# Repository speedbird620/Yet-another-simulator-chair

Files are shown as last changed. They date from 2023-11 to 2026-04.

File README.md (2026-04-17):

# Yet another simulator chair

## Abstract 

This is an open source simulator project where an IKEA chair has been modified into a dual control joystick. The primary purpose is to provide students with an opportunity to train, for example, using Condor gliding simulator. From the basic flight training, to fine tuning the art thermalling and cross country. All in reach for the reasonable DIY-handy individual.

Note that the chair can easily be used for both motor and rotorcraft as well: you simply tighten the wing nut and neutralize the spring that simulates the glider´s air brake return force.

## Background

This project is sprang from the disappointment of using a joystick bought from an electronics store for 120€. Being a glider pilot for the last +30 years I do become annoyed when I can´t catch the thermals properly in the Condor gliding simulator. Or at least I blamed the joystick.

I started to think outside the box: How can I do this better with a reasonable budget? This page is my answer to this question.

After a few prototypes, I arrived at a solution where a control assembly is mounted on a chair. The prototypes proved that adequate control was feasible with surprisingly good flight control dynamics: you tend to forget that you are in a simulator when using a VR-headset. 

_The first example in the prototype series during flight trials._





_The first example in the prototype series being built._



The second iteration is utilising an Arduino Micro and hall sensors for the flight controls. Then an idea emerged of creating a more comfortable solution which can be reproduced larger numbers and how simulators can be a part of pilot training, especially for us who lives in a country that only allow flight from April to October.

The requirements for the simulator:
 - The parts shall be available in general stores (as far as possible)
 - A simple yet durable construction
 - Dual control: stick, rudder and airbrake
 - Airbrake shall be able to be used as throttle and collective after minor alteration
 - Tow cable release
 - Position of pedals are adjustable

## Current project status

The list of built YAS-chairs:
- sn 001: ÖSFK at ESSZ, first prototype
- sn 002: Private outside Långtora, second prototype.

Follow the progress of sn 002 here: https://photos.google.com/share/AF1QipPOUyROssQ330J8llb0_tj2pAIGFBXjLDJpcaH-N3GVbZG6ntuDcigQtvq15HF2ng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

Prototype series sn 003 - 010:
- sn 003: Swedish Soaring Federation, Ålleberg
- sn 004: Private, Forssa
- sn 005: Private, Forssa
- sn 006: Private, Forssa
- sn 007: Private, Ludvika
- sn 008: Borås Segelflygklubb
- sn 009: kit available
- sn 010: kit availablel

_The assembly process of sn 003. For pictures in a sort of a timeline, se assembly.pfd above._








_Second prototype, sn 002._



_Airbrake and tow release of second prototype, sn 002._



## Electronics, "the magic stuff"

The electronics and software package that will simulate a joystick using the built-in drivers in Windows. Either you can get the stuff in the bill of materials, put things together and apply the Arduino libraries. Or feel free to use it as a creative compass for your own build.

The skill level required is an average glider pilot with limited soldering skill. After all this aren’t rocket science, just simulator science.

The electronics and software package contains:
 - Design schematic (open source) for Arduino Leonardo or Arduino Micro (ATMEGA32U4)
 - Software and libraries (open source)
 - Bill of material for recommended components to order 

Please note: At first, I used potentiometers which broke pretty much instantly. Since then hall sensors are used which works excellently. So, if you are opting for potentiometers, please be aware of the potential limitations.

To make things easier I have developed a bespoke PCB-adaptor between Arduino and electrical connectors as well as a bespoke PCB-adaptor for the hall sensors recommended in the bill of material. Eventually you will be able to order these PCB´s.

_PCB for adaptor Arduino and hall sensor._



_PCB-adaptor for Arduino Leonardo or Arduino Micro. The picture shows a PCB with Leonardo, hall sensor and switches (examples)._



## Flight control assembly

The flight control assembly is designed to fit onto a [POÄNG](https://www.ikea.com/se/sv/cat/poaeng-serie-07472/) from IKEA. Please see the blue prints in the DXF-folder in the file repository above for the pieces to cut out. Above you will also find a list of material to buy in the local hardware store (hinges, washers, nuts, screws, bicycle parts etc.)

We plan to offer a kit with CNC-cutout parts from plywood but this is progress right now. Meanwhile, if you have access to a CNC machine or a laser cutter, please feel free to download the DXF files and make simulator youself.

_The chair with the flight control assembly mounted to POÄNG. View from the side._



_View from back._



_Below are some of the mounting instructions._






Installing the electronics

In order to install the hall sensors, a few 3D printed items have been developed. Please find the STL-files in the above repository. 

_The holder for the Hall-sensor, arm, link and bracket._



_From the back side._



_A base for the PCB so you can test in on a workingbench._



_An overview of the parts to print._



Stay tuned ....

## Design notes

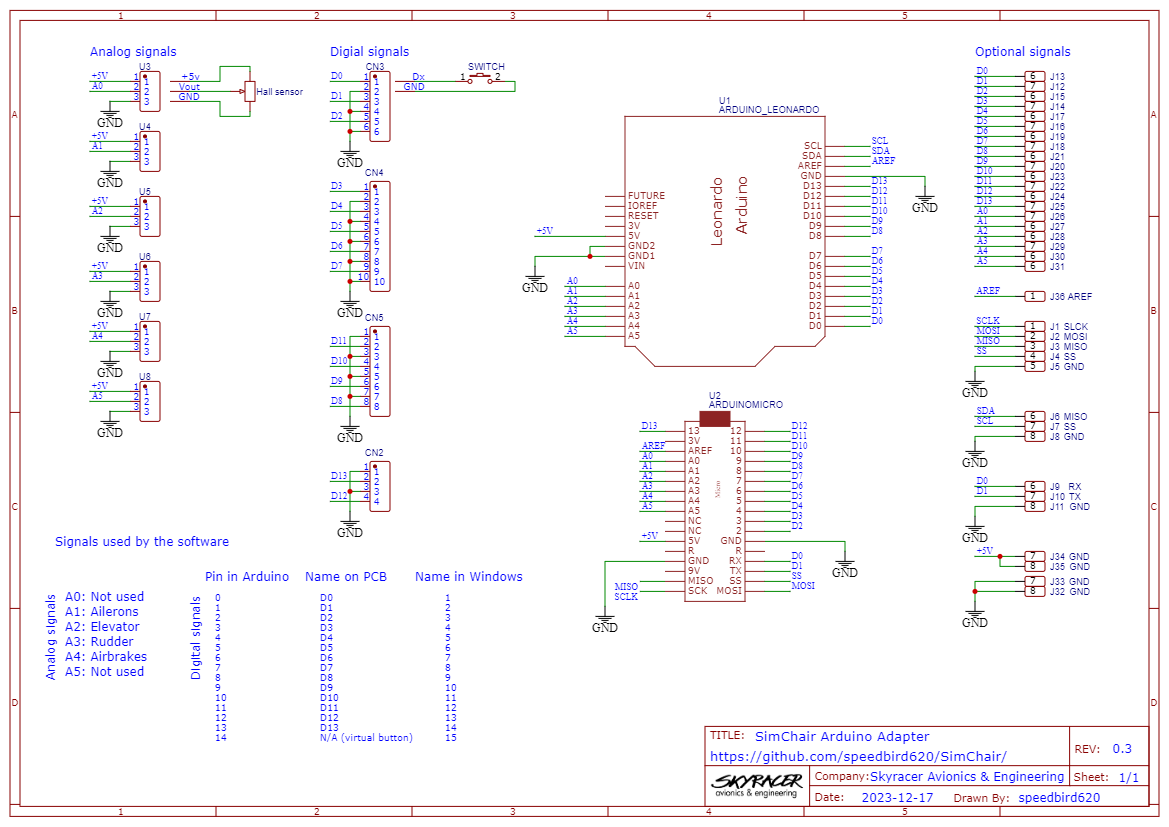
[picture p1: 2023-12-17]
Schematic_SimChair.png

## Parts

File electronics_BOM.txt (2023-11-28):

Description			Vendor	 	Art. No.	Ammount
Terminal block 3 ways		Farnell	 	2493670		12
Terminal block 2 ways		Farnell	 	3810323		14
Tyerminal plug 3 ways		Farnell	 	2575234		12
Tyerminal plug 2 ways		Farnell	 	3810196		14
Pin header, 20 pins		Farnell	 	3881577		2
PCB Receptacle, 12 pins		Farnell	 	1593465		1
PCB Receptacle, 8 pins		Farnell	 	1593463		2
PCB Receptacle, 6 pins		Farnell	 	1668352		1
Wire ferrule 1 mm²		Farnell	 	841201		1
SKX, 2 x 0.75mm2, 25m		Biltema	 	35-433		1
RDO, 3 x 1mm2, 10m		Biltema	 	44-838		1
Hall Effect Sensor, 60°		Farnell		2319671		4
Leonardo			Farnell		2133070		1
USB micro cable			Farnell		2907930		1
Capacitor, 10 µF, 16 V, 0805	Farnell		3013453		4

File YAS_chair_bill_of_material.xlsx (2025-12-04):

Main parts
Description | Vendor | Art. No. | Count | Comment
Poäng | IKEA | 692.408.23 | 1
Plyfa-kit | Högbergs |  | 1
Hardware store stuff
Description | Vendor | Art. No. | Count | Comment
Hinge 1501, 50x39 mm | Habo | 6809 | 7
Wooden joist 1" x 1" | Beijer |  | 2 | 4.2 m, chair guide
Formplywood base plate, 850x2500x12 | Beijer |  | 1
Terminal block 1.5 mm | Biltema | 35-810 | 1 | For securing the bike wires
Rubberbands | Biltema | 34-219 | 1 | ~ 1 m, as pedal springs
Ball bearing, 6000-2RS, 10x26x8 mm | Biltema | 41-412 | 4 | To be encapsulated in 3D-print
Brake wire 1.6mm | Local bike shop |  | 5 | 2 meter brake wire 1.6 mm
Bowden cable 2/6 mm | Local bike shop |  | 2 | Housing the brake wire (2 meters)
Luxorparts Neodyn magnet 8 mm | Kjell.com | 50070 | 2 | Airbrake over-locking
Silicone tube 6 mm x 20 mm | Biltema | 15-330 | 1 | Wheel brake
Wooden glue |  |  | 1 | Not mandantory
Countersunk wooden screw 3.2x20 FXB | Beijer |  | 1 | Pack of 200
Countersunk wooden screw 3.2x35 FXB | Beijer |  | 2 | Pack of 200
Assembly screw 4.2 x 13 mm | Beijer |  | 1 | Pack of 200
Assembly screw 4.2 x 19 mm | Beijer |  | 1 | Pack of 200
M4 x 30 mm Allen screw | Electrokit | 1154354 | 20 | For links to hallsensors
M4 nut | Electrokit | 1874659 | 25 | For links to hallsensors
M6 x 36 carriage bolt |  |  | 1 | Joint for break leaver
M6 wingnut | Biltema | 89-288 | 1 | Joint for break leaver
M6 washer |  |  | 5 | Joint for break leaver
M10x1.5 nut stainless | Biltema | 89-934 | 12 | Stick assembly and rear spedals
M10x1.5 washer stainless | Biltema | 89-423 | 25 | Stick assembly and rear spedals
M10x1.5 threaded rod 1 m | Biltema | 19-340 | 1 | Stick assembly and rear spedals
Cable duct, 12 x 32 x 2000 | Beijer
Misc wooden screws
Electronics
Description | Vendor | Art. No. | Ammount
Terminal block 6 ways | electrokit.com | 41017343 | 2 | For breakout board (switches)
Terminal block 4 ways | electrokit.com | 41017342 | 4 | For breakout board (switches)
Terminal block 3 ways | electrokit.com | 40210022 | 12 | For breakout board (hall sensors)
Terminal plug 3 ways | electrokit.com | 40210012 | 12 | To hall sensors
Terminal plug 2 ways | electrokit.com | 40210011 | 14 | To switches
Slide potentiometer | electrokit.com | 40920011 | 1 | Trim control
Pin header 40 pins | electrokit.com | 41001167 | 2 | For Leonardo
PCB Receptacle 12 pins | electrokit.com | 41010580 | 1 | For breakout board (Leonardo)
PCB Receptacle 8 pins | electrokit.com | 41002450 | 2 | For breakout board (Leonardo)
PCB Receptacle 6 pins | electrokit.com | 41010579 | 1 | For breakout board (Leonardo)
USB micro cable 3 m | electrokit.com | 41015492 | 1 | Leonardo to PC
Wire ferrule 1 mm² | electrokit.com | 41011403 | 150
SKX, 2 x 0.75mm2, 10m | Biltema | 35-433 | 1 | Cable to hall sensors
RDO, 3 x 1mm2, 5m | Biltema | 44-838 | 1 | Cable to switches
Micro switch on-(on) | electrokit.com | 41002040 | 1 | Tow release
Micro switch (on)-off-(on) | electrokit.com | 41015339 | 3 | Flap control, reset, etc.
Pushbutton off-(on) | electrokit.com | 41013042 | 4 | Gear, pause, smoke etc.
Hall Effect Sensor, 60° | Farnell | 2319671 | 4
Leonardo | Farnell | 2133070 | 1
Capacitor, 10 µF, 16 V, 0805 | Farnell | 3013453 | 4 | On the hall sensor PCB
PCB´s
PCB Leonardo | mail@skyracer.net |  | 1
PCB Hall effect sensor | mail@skyracer.net |  | 4
Remote stick PCB | mail@skyracer.net |  | 1
3D-prints
3D-printed brackets (~45 items) |  |  | 1
Remote stick | Langer (Thiniverse) |  | 1 | Optional
Tools
Ferrule crimp tool
Drill 2.5 mm |  |  |  | For pre-drilling so the wood does not crack
Drill 4 mm
Drill 6.5 mm
Drill 8 mm
M3x0.5 thread tap |  |  |  | To clean the threads in 3D printed parts
M4x0.7 thread tap |  |  |  | To clean the threads in 3D printed parts
M10x1.5 thread tap |  |  |  | To clean the threads in 3D printed parts
Set of allen keys |  |  |  | Not just the 4 mm IKEA key
Screwdrivers: PH1, PH2, PZ1, PZ2
2x 15 keys (for the M10 nuts)

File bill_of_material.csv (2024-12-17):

The wood stuff
Base plate 12 mm plywood: 2400mm x 800 mm
Rear POÄNG aligner: 2 pcs 1" x 2" x spar 1400 mm
Front POÄNG aligner: 2 pcs 1" x 2" x spar 900 mm
Flight control stick: 2 pcs 1" x 1" x spar 520 mm
The hardware store stuff
Description | Vendor | Art. No. | Ammount | Comment
Hinge 1501 | 50x39 mm | Habo | 6809 | 14
Ball bearing | Biltema | 41-412 | 4 | 6200-2RS 10x26x8 mm
Terminal block 1.5 mm² | Biltema | 35-810 | 1
Rubberbands | Biltema | 34-219 | 1
Break wire 199 cm | Biltema | 27-802 | 3
Break cable 1.5 mm² | Biltema | 27-804 | 1
Washer M10 stainless 10 pcs | Biltema | 89-934 | 2
Threaded rod M10 100 cm | Biltema | 19-340 | 1
Luxorparts Neodyn magnet 8 mm | Kjell.com | 50070 | 2
PVC-tube 6 mm (inside) x 20 mm | Biltema | 15-330 | 1
The electronics stuff
Description | Vendor | Art. No. | Ammount
Terminal block 6 ways | electrokit.com | 41017343 | 2
Terminal block 4 ways | electrokit.com | 41017342 | 4
Terminal block 3 ways | electrokit.com | 40210022 | 12
Terminal plug 3 ways | electrokit.com | 40210012 | 12
Terminal plug 2 ways | electrokit.com | 40210011 | 14
Slide potentiometer | electrokit.com | 40920011 | 1
Pin header | 40 pins | electrokit.com | 41001167 | 2
PCB Receptacle | 12 pins | electrokit.com | 41010580 | 1
PCB Receptacle | 8 pins | electrokit.com | 41002450 | 2
PCB Receptacle | 6 pins | electrokit.com | 41010579 | 1
USB micro cable 3 m | electrokit.com | 41015492 | 1
Wire ferrule 1 mm² | Farnell | 841201 | 1
SKX, 2 x 0.75mm2, 25m | Biltema | 35-433 | 1
RDO, 3 x 1mm2, 10m | Biltema | 44-838 | 1
Hall Effect Sensor, 60° | Farnell | 2319671 | 4
Leonardo | Farnell | 2133070 | 1
Capacitor, 10 µF, 16 V, 0805 | Farnell | 3013453 | 4

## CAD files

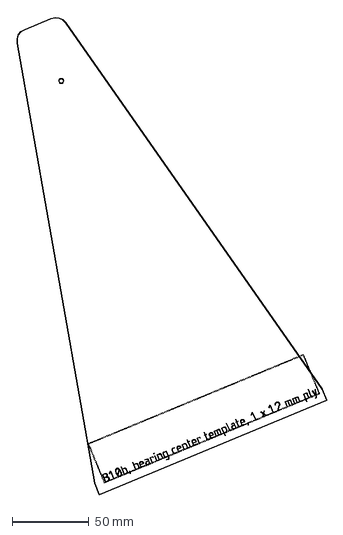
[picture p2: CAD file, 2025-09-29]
dxf/B10b.dxf
202.0 x 310.9 mm

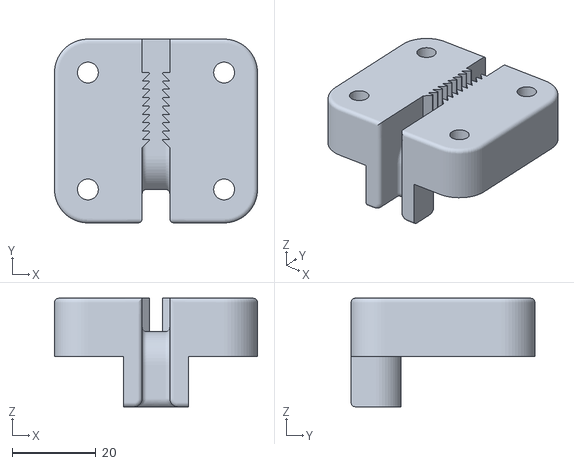
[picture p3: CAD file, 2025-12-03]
stl/G5.stl
48.6 x 44.0 x 26.0

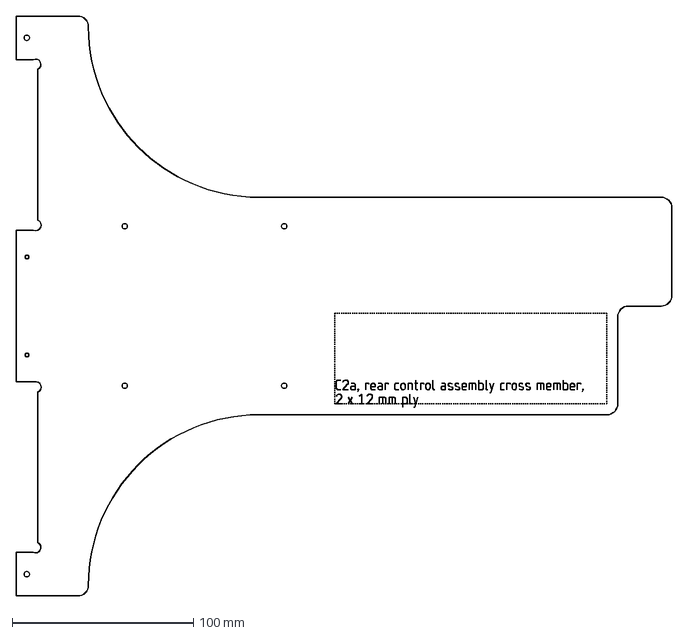
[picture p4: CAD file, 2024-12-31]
dxf/C2a.dxf
362.0 x 320.0 mm

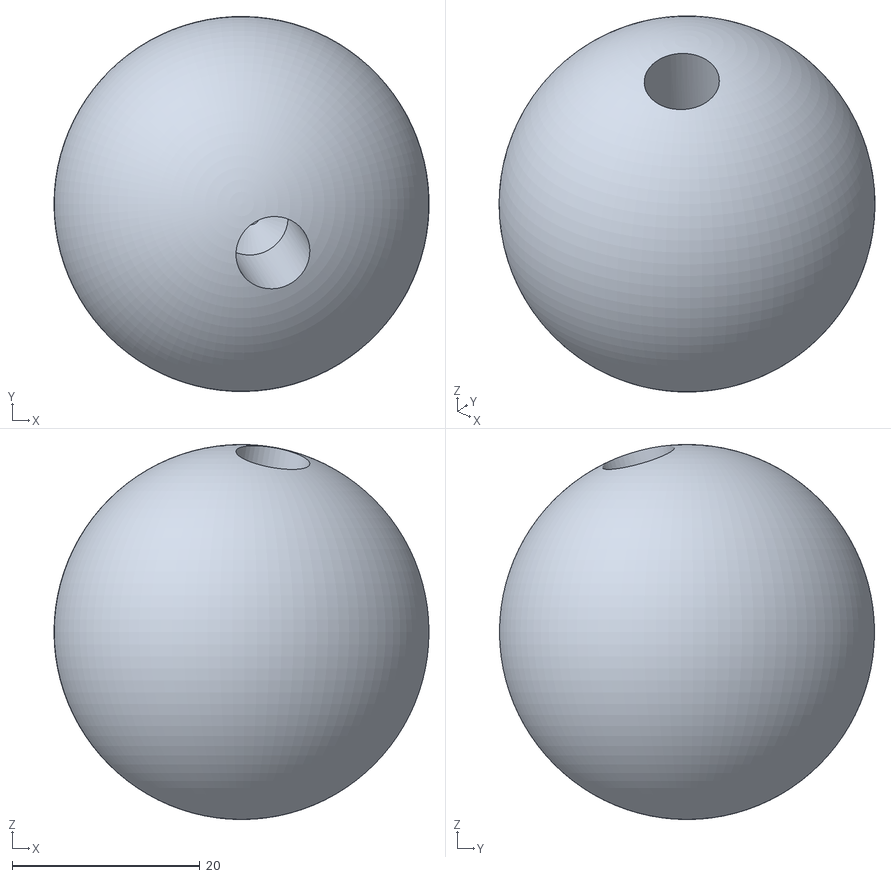
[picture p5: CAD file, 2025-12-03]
stl/H6.stl
40.0 x 40.0 x 40.0

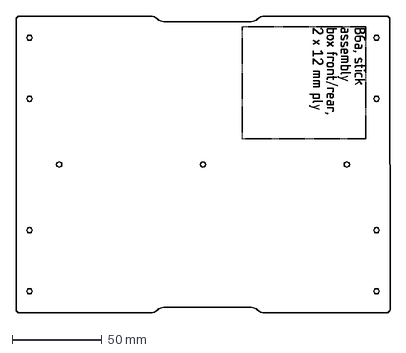
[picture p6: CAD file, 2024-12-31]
dxf/B6a.dxf
208.0 x 165.0 mm

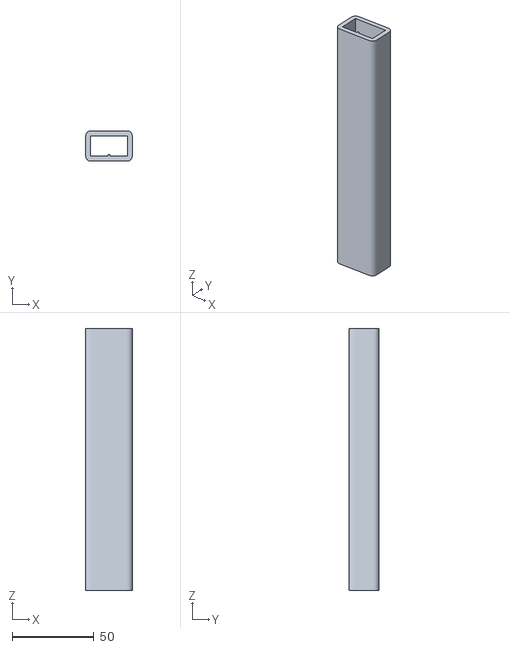
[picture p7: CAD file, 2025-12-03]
stl/H2.stl
28.5 x 18.5 x 160.0

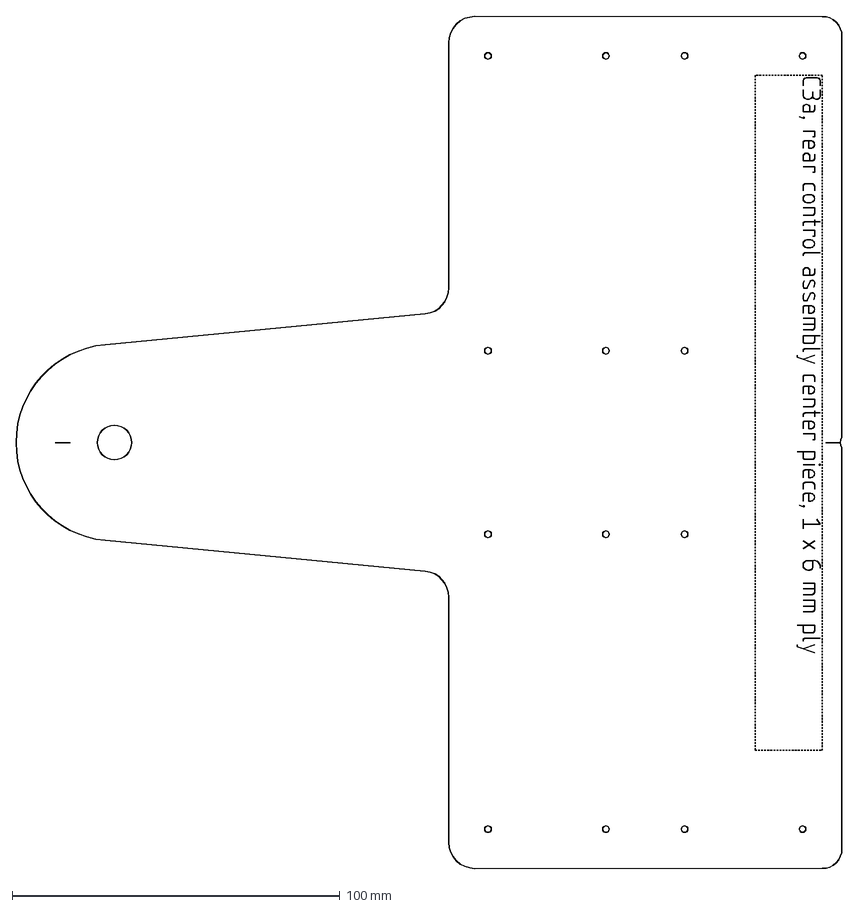
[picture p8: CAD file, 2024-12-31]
dxf/C3a.dxf
252.0 x 260.0 mm

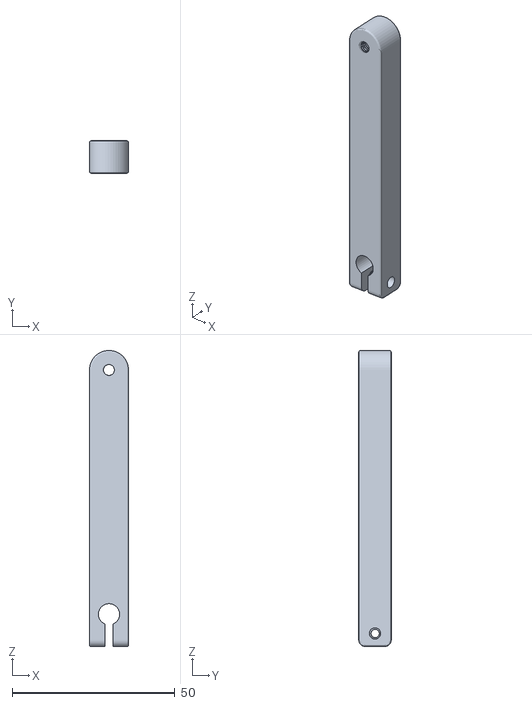
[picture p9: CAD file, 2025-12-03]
stl/F9.stl
12.0 x 10.0 x 90.9

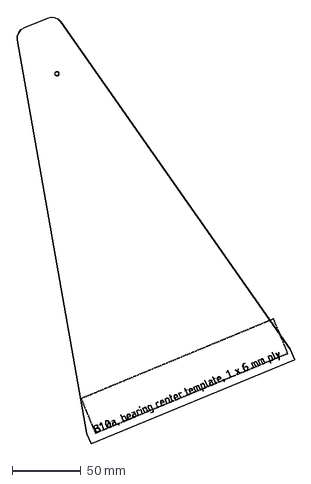
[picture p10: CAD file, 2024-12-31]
dxf/B10a.dxf
202.0 x 310.9 mm

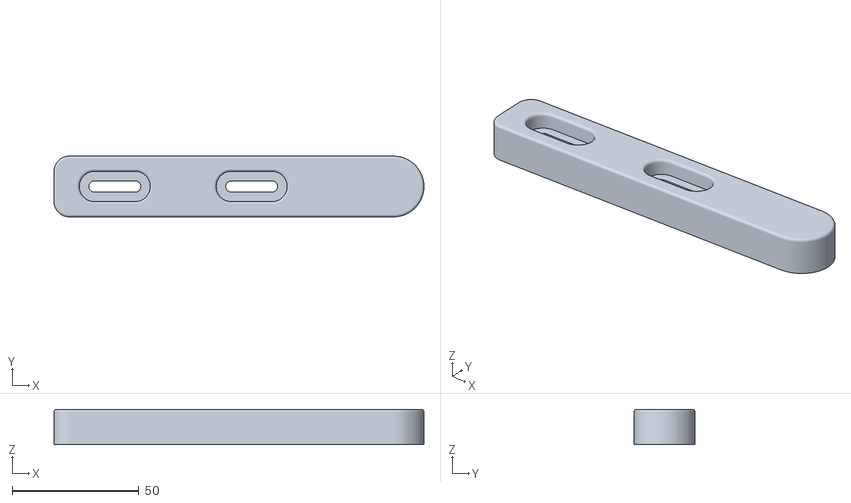
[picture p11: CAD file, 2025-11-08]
stl/G4.stl
146.0 x 24.0 x 14.0

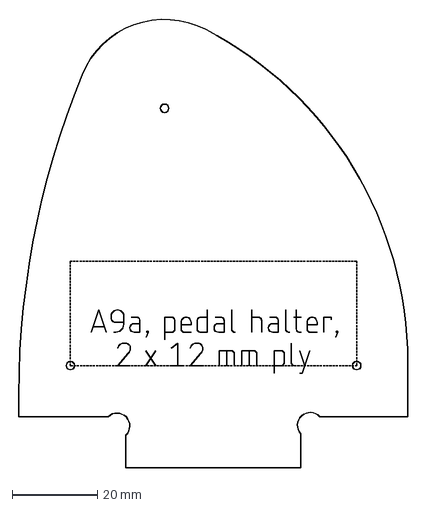
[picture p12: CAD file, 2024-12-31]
dxf/A9a.dxf
91.8 x 106.0 mm

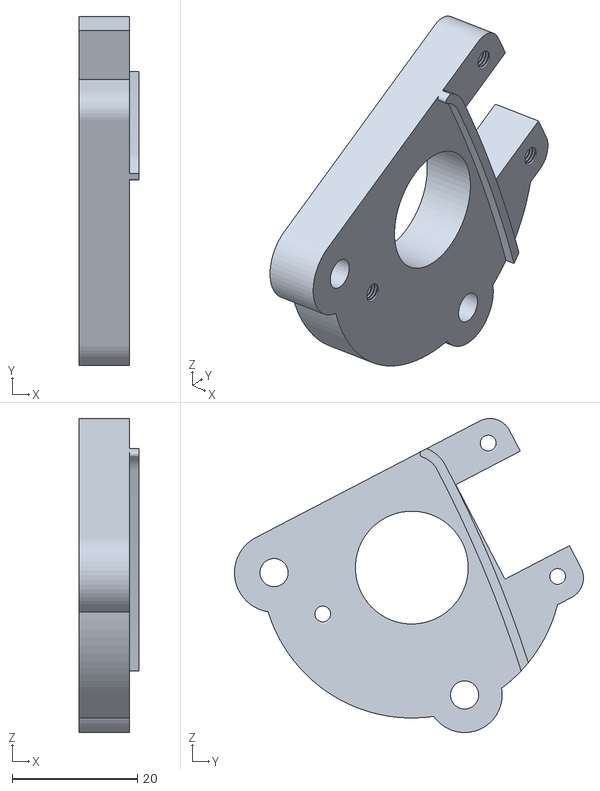
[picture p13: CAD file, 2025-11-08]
stl/F11.stl
9.50 x 55.7 x 50.1

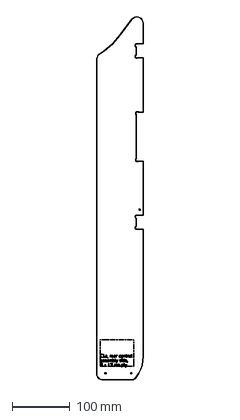
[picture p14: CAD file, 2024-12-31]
dxf/C1a.dxf
80.0 x 628.1 mm

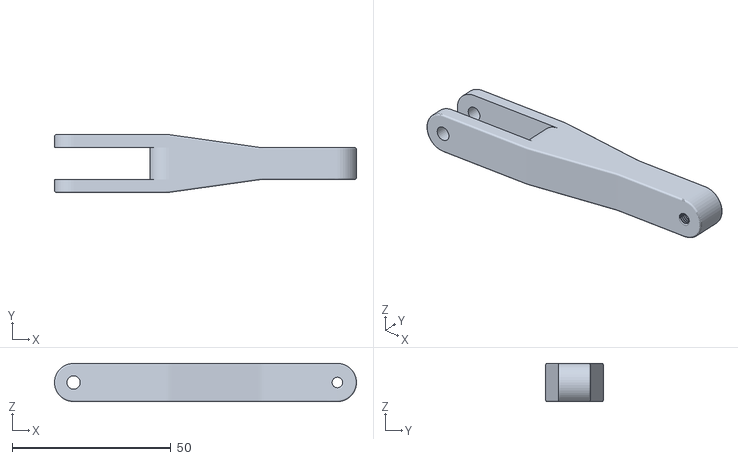
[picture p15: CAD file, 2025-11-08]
stl/F10.stl
95.0 x 18.2 x 12.0

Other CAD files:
dxf/D1a.dxf
stl/F12.stl
dxf/A5.dxf
stl/F3.stl
dxf/A1.dxf
dxf/A2.dxf
dxf/A3.dxf
dxf/A4.dxf
dxf/A6.dxf
dxf/A7.dxf
dxf/A8.dxf
dxf/A9.dxf
dxf/B1.dxf
dxf/B10.dxf
dxf/B2.dxf
dxf/B3.dxf
dxf/B4.dxf
dxf/B5.dxf
dxf/B6.dxf
dxf/B7.dxf
dxf/B8.dxf
dxf/B9.dxf
dxf/C1.dxf
dxf/C2.dxf
dxf/C3.dxf
dxf/D1.dxf
dxf/D2.dxf
dxf/D3.dxf
dxf/D4.dxf
dxf/D5.dxf
dxf/D6.dxf
dxf/E1.dxf
dxf/E2.dxf
dxf/E3.dxf
dxf/E4.dxf
dxf/E5.dxf
dxf/E6.dxf
dxf/E7.dxf
dxf/E8.dxf
dxf/E9.dxf
dxf/old/A1.dxf
dxf/old/A2.dxf
dxf/old/A3.dxf
dxf/old/A4.dxf
dxf/old/A5.dxf
dxf/old/A6.dxf
dxf/old/A7.dxf
dxf/old/A8.dxf
dxf/old/A9.dxf
dxf/old/B1.dxf
dxf/old/B10.dxf
dxf/old/B2.dxf
dxf/old/B3.dxf
dxf/old/B4.dxf
dxf/old/B5.dxf
dxf/old/B6.dxf
dxf/old/B7.dxf
dxf/old/B8.dxf
dxf/old/B9.dxf
dxf/old/C1.dxf
dxf/old/C2.dxf
dxf/old/C3.dxf
dxf/old/D1.dxf
dxf/old/D1a.dxf
dxf/old/D2.dxf
dxf/old/D3.dxf
dxf/old/D4.dxf
dxf/old/D5.dxf
dxf/old/D6.dxf
dxf/old/E1.dxf
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

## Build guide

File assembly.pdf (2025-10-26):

# Please note that the colour of the parts are not consistent in these

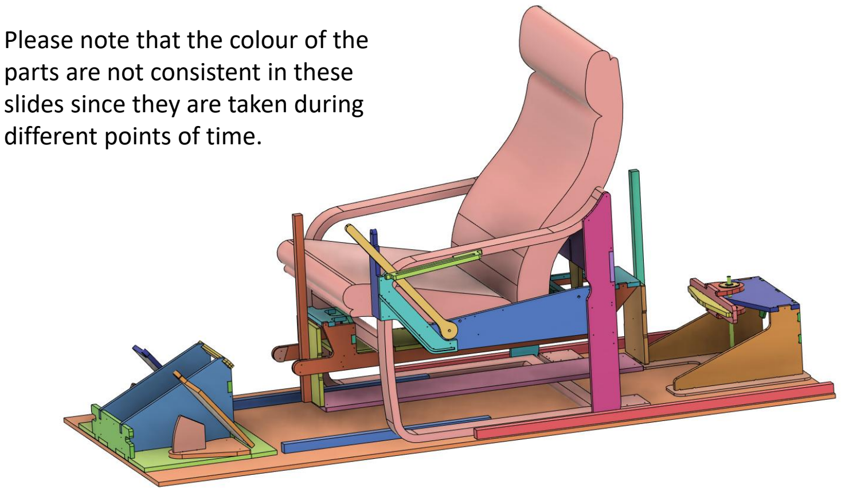
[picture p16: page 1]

# slides since they are taken during

different points of time.

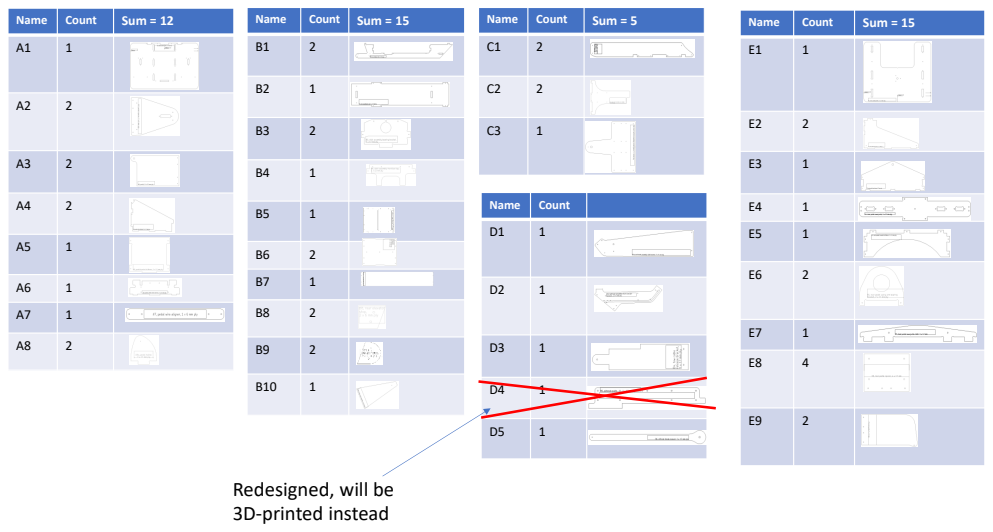
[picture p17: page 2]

F1, 2x

F2, 2x

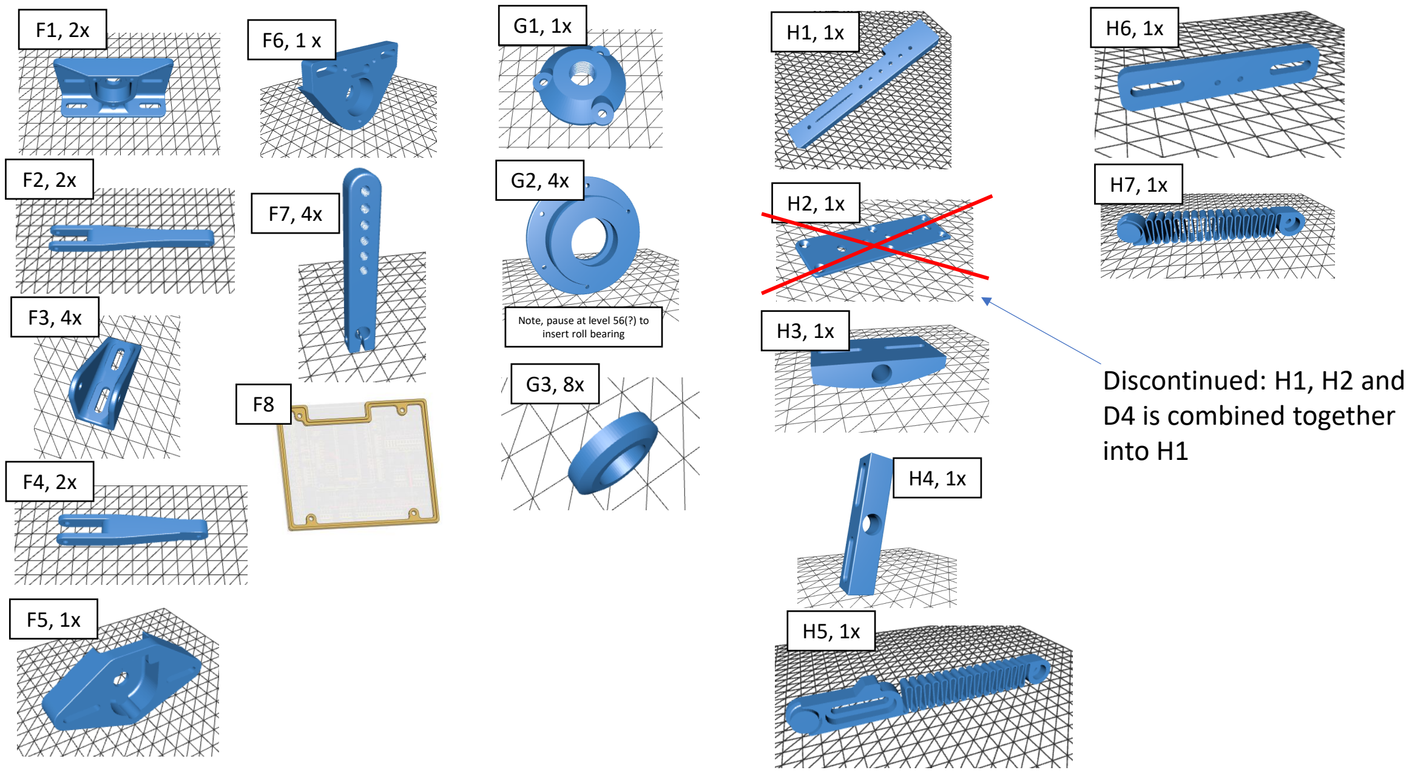
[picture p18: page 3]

F3, 4x

F4, 2x

G1, 1x

G2, 4x

G3, 8x

H1, 1x

H2, 1x

F5, 1x

F6, 1 x

Note, pause at level 56(?) to insert roll bearing

F7, 4x

H3, 1x

H4, 1x

F8

H5, 1x

H6, 1x

H7, 1x

# Discontinued: H1, H2 and D4 is combined together into H1

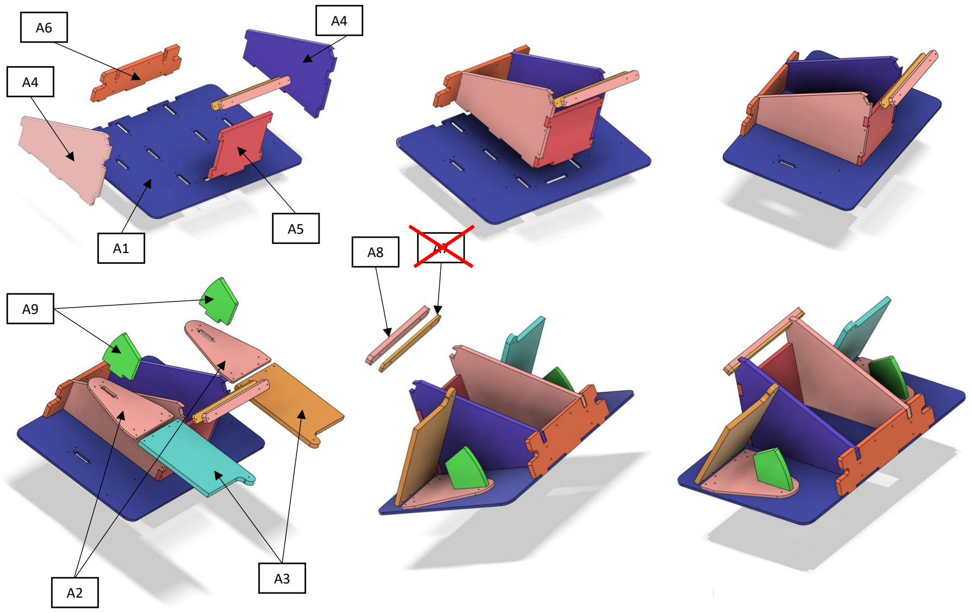
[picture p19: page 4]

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
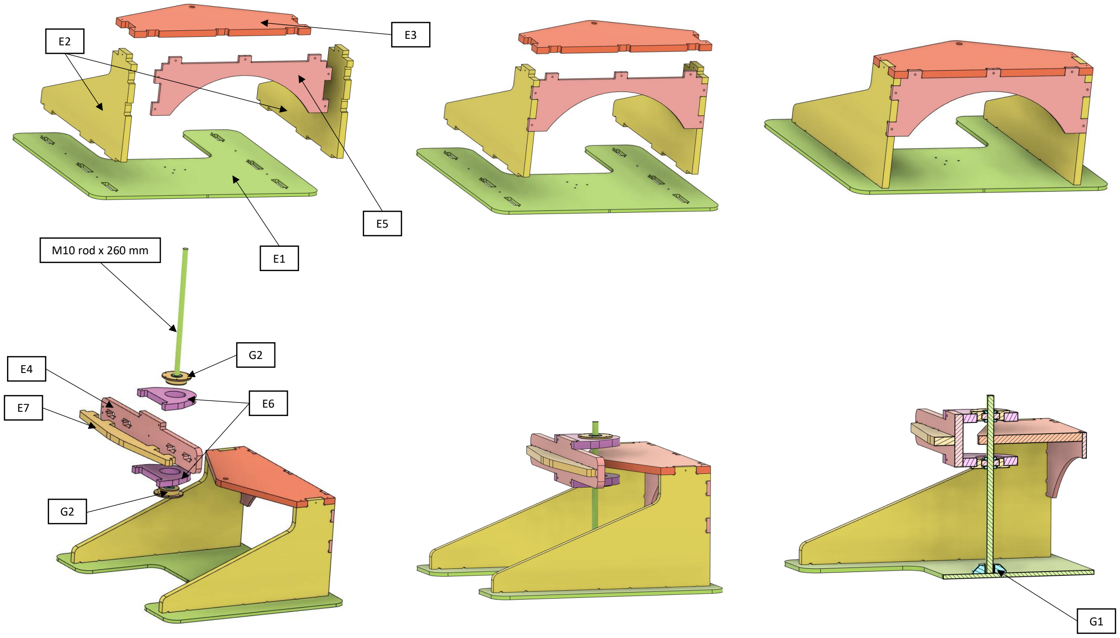
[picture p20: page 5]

E1

E2 | E3

E5

E4

E7 | E6 G2

G2

G1

M10 rod x 260 mm

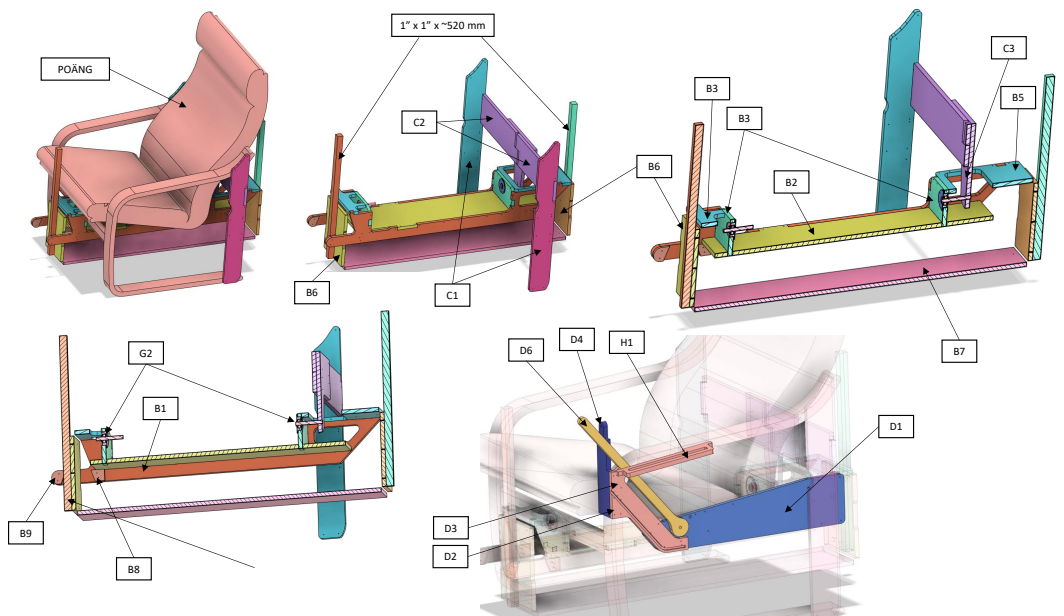
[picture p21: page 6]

This is to simulate the air brake leaver lock.

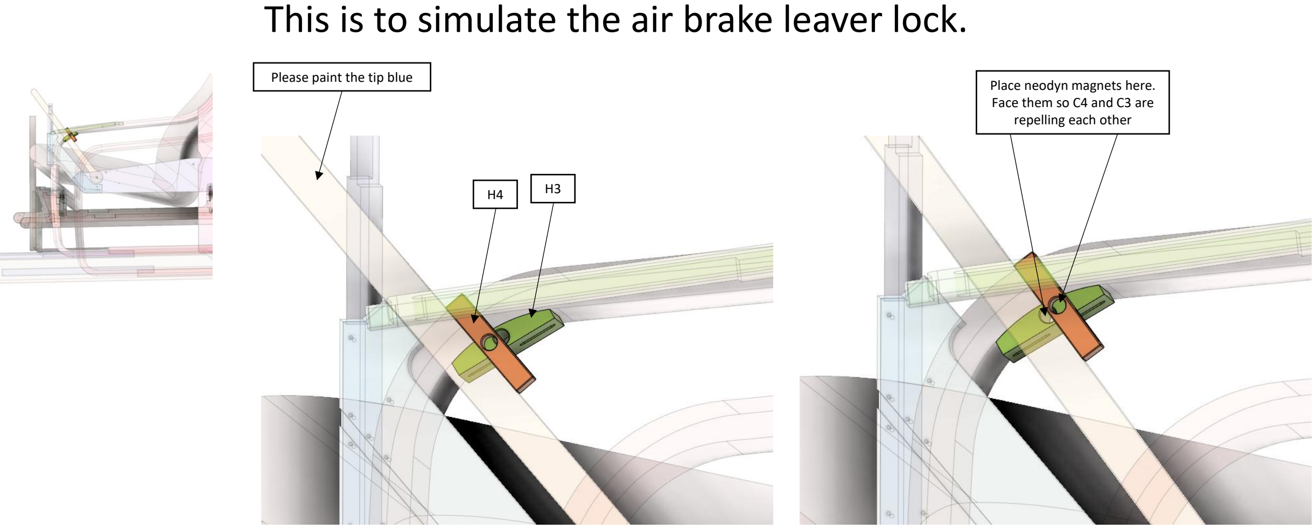
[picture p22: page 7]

H4 H3

Place neodyn magnets here. Face them so C4 and C3 are repelling each other

Please paint the tip blue

# Simulating wheel brake

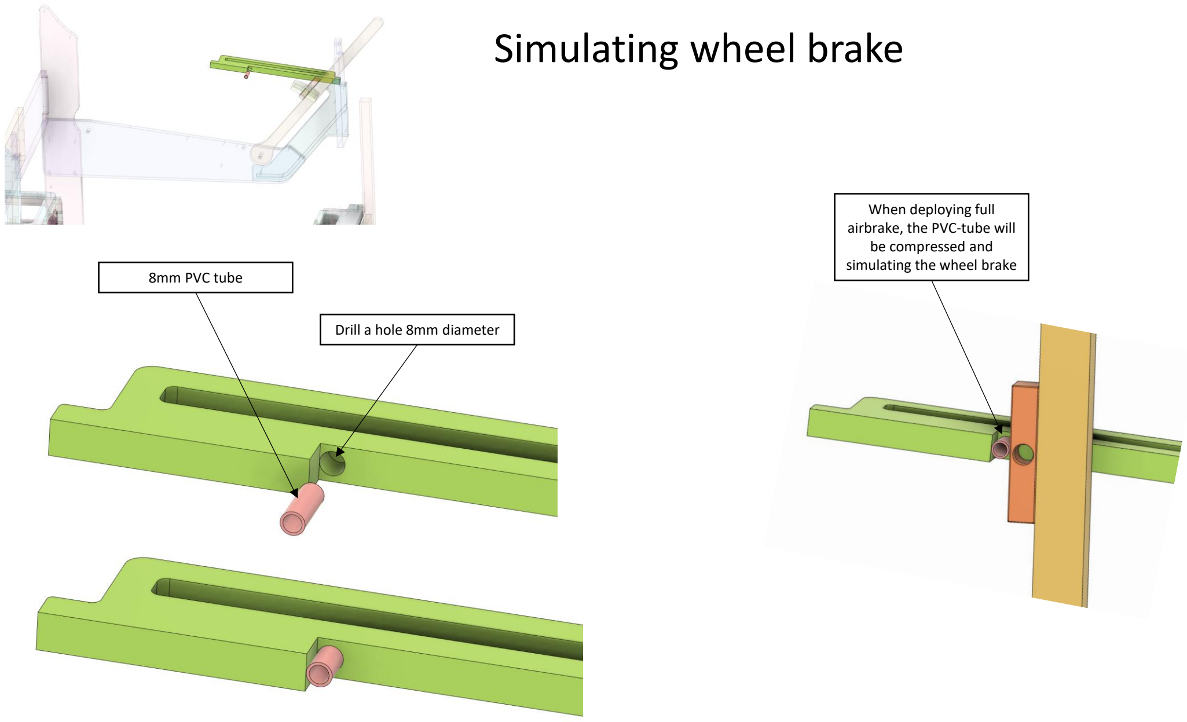
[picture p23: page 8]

Drill a hole 8mm diameter

8mm PVC tube

When deploying full
airbrake, the PVC-tube will be compressed and
simulating the wheel brake

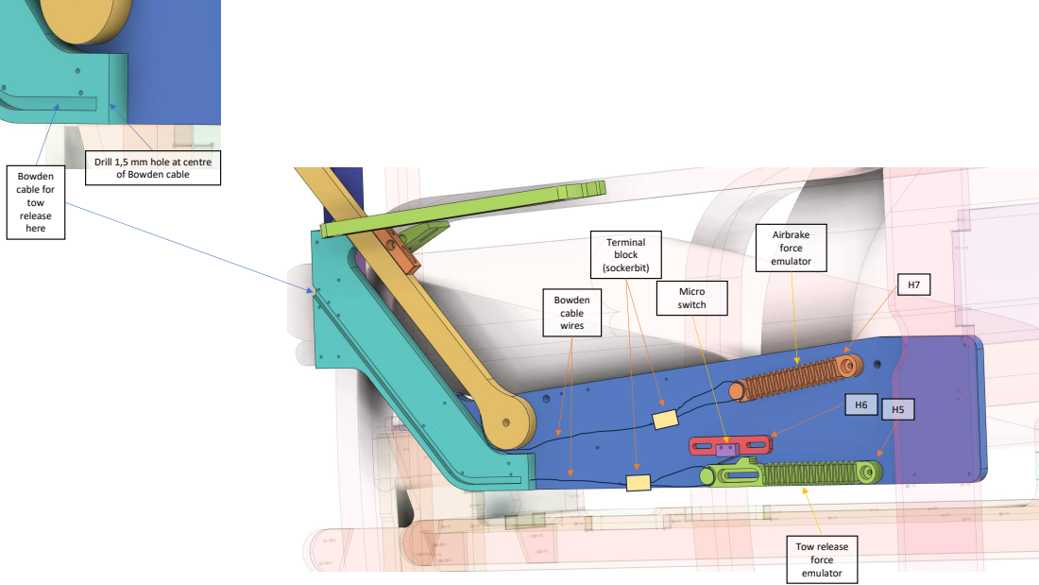
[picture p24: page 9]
Bowden; of Bowden cable; cable for tow release here; Bowden cable wires; Terminal block (sockerbit); Micro switch; Airbrake force emulator; Tow release force emulator

Drill 1,5 mm hole at centre

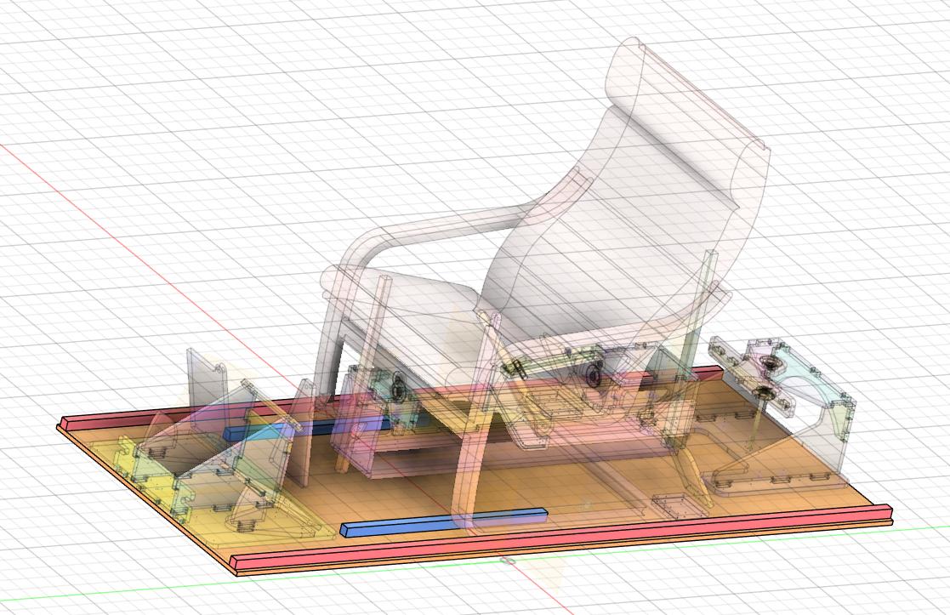
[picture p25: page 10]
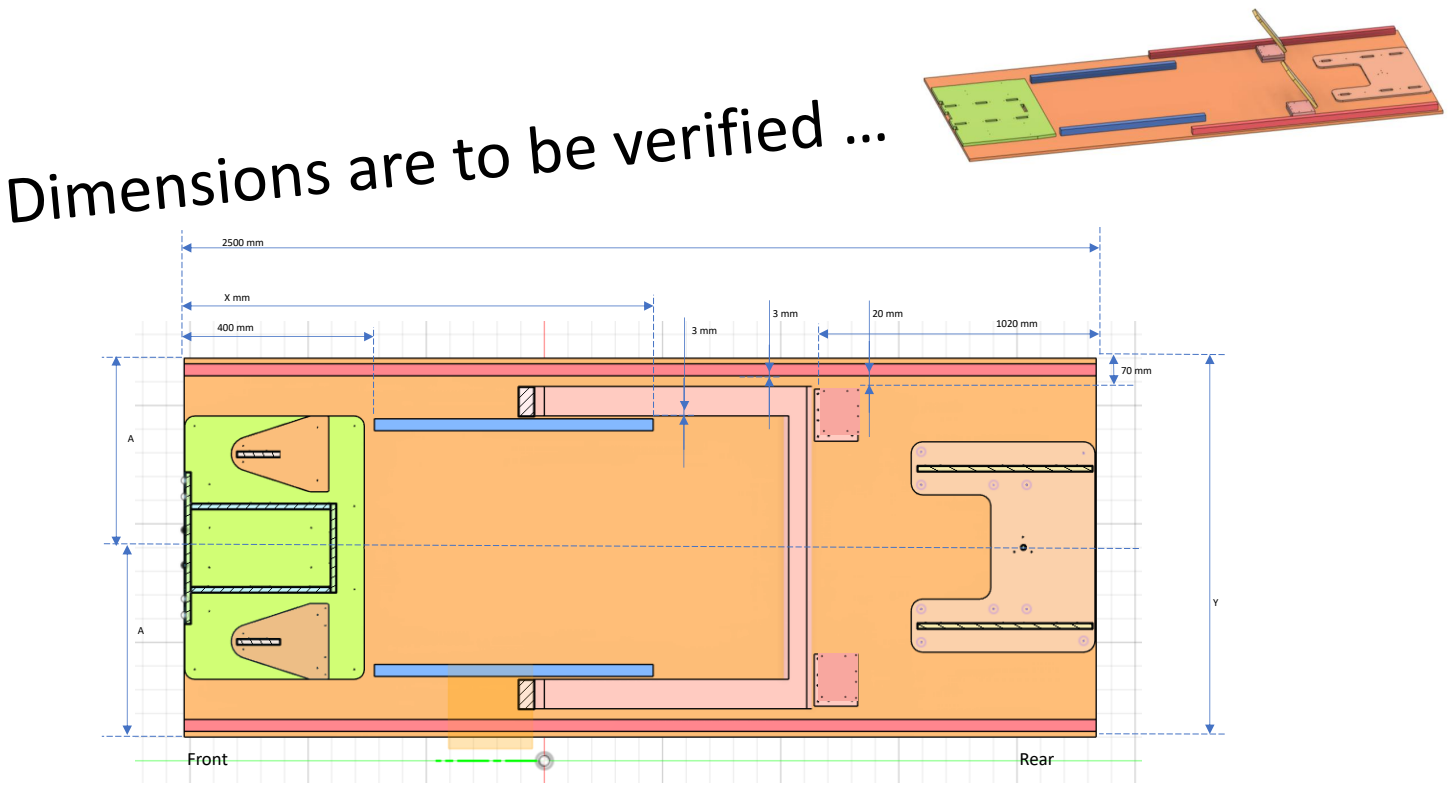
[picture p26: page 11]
Front; Rear

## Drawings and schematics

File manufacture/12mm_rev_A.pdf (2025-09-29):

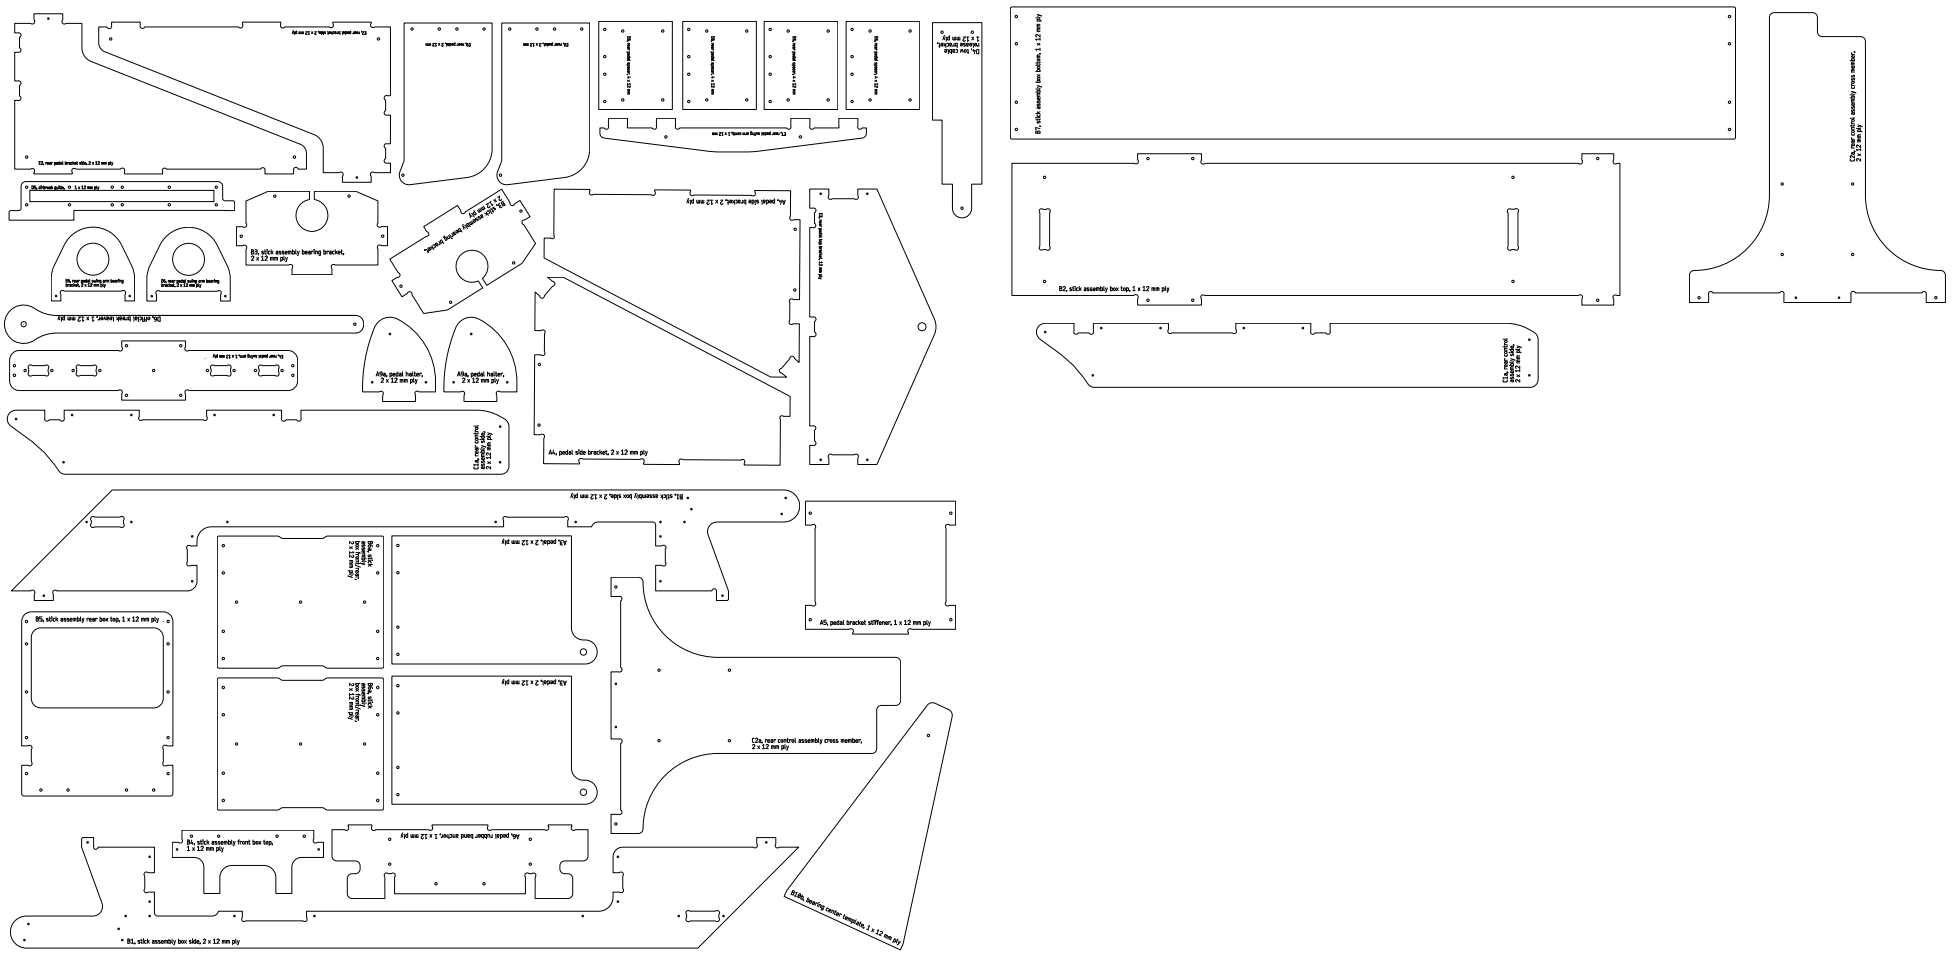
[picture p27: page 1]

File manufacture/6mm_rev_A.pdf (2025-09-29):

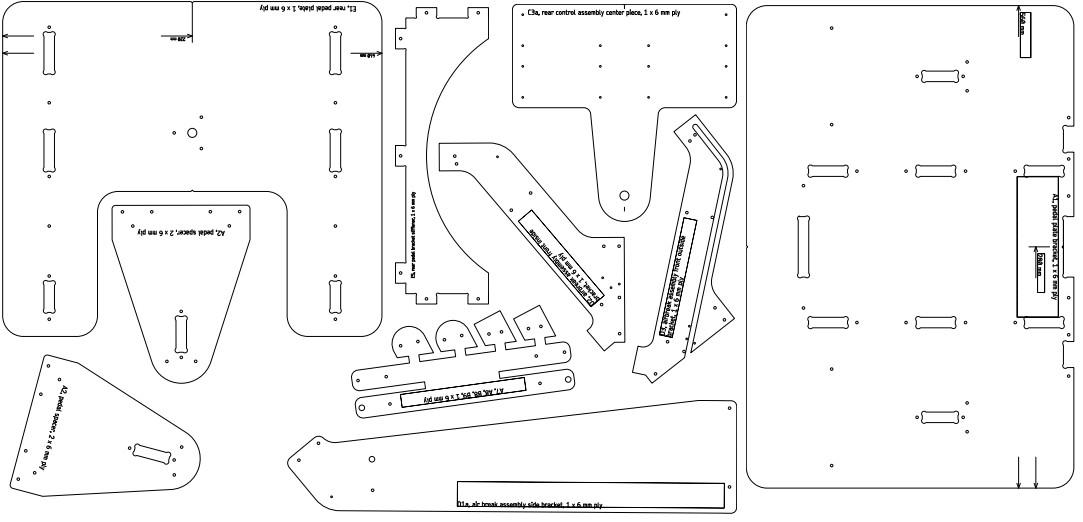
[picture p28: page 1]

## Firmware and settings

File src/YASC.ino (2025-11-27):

// Program bespoke to the SimChair
// Arduino Micro or Leonardo
//
// avionics@skyracer.net
//
// 0.1 - First version
// 0.2 - Added comments and configurable variable
// 0.3 - Added digital signals, now: 15 digital and 4 analog channels
// 0.4 - Added a secondary joysticvk, now: 2 x (15 digital and 4 analog channels)
// 0.5 - Added debug mode
//
// https://github.com/MHeironimus/ArduinoJoystickLibrary/tree/version-1.0
// https://mheironimus.blogspot.com/2015/11/arduino-joystick-library.html
//------------------------------------------------------------

#include <Joystick.h> 

Joystick_ Joystick1(0x03, //hid report id
  JOYSTICK_TYPE_GAMEPAD, //joystick type
  15, //button count
  0, //Hsw 0-2
  true, //x
  true, //y
  true, //z
  false, //rx
  false, //ry
  false, //rz
  false, //rudder
  true, //Airbrake
  false, //throttle
  false, //brake
  false); //steering

Joystick_ Joystick2(0x04, //hid report id
  JOYSTICK_TYPE_GAMEPAD, //joystick type
  15, //button count
  0, //Hsw 0-2
  true, //x
  true, //y
  true, //z
  false, //rx
  false, //ry
  false, //rz
  false, //rudder
  true, //Airbrake
  false, //throttle
  false, //brake
  false); //steering

  // Configuration variables, FALSE: not reverse, TRUE: reversed
  bool XAxisReverse = true;
  bool YAxisReverse = true;
  bool ZAxisReverse = true;
  bool AirbrakeReverse = true;
  bool TrimReverse = false;
  bool WheelBrakeOnAirbrake = true; //Set false if Airbrake is used as throttle
  bool DebugMode = true;

  // Initialize internal variables
  int XAxis = 0;
  int YAxis = 0;
  int ZAxis = 0;
  int Trim = 0;
  int Airbrake = 0;
  int MaxAirbrake = 0;
  int MinAirbrake = 1024;
  float AirbrakeRatio = 0.0;
  
void setup() 
  {
  // Starting the joystick engine
  Joystick1.begin();
  Joystick2.begin();
  // Setting up IO´s
  pinMode(0, INPUT_PULLUP);
  pinMode(1, INPUT_PULLUP);
  pinMode(2, INPUT_PULLUP);
  pinMode(3, INPUT_PULLUP);
  pinMode(4, INPUT_PULLUP);
  pinMode(5, INPUT_PULLUP);
  pinMode(6, INPUT_PULLUP);
  pinMode(7, INPUT_PULLUP);
  pinMode(8, INPUT_PULLUP);
  pinMode(9, INPUT_PULLUP);
  pinMode(10, INPUT_PULLUP);
  pinMode(11, INPUT_PULLUP);
  pinMode(12, INPUT_PULLUP);
  pinMode(13, INPUT_PULLUP);
  }

void loop() 
  {
  //  Reading analog signals

  YAxis = analogRead(A0);
  if (YAxisReverse) {Joystick1.setYAxis(YAxis);}             //  The input is normal (due to mounting of the sensor)
    else {Joystick1.setYAxis(1024-YAxis);}                   //  The input is reversed (due to mounting of the sensor)

  XAxis = analogRead(A1);
  if (XAxisReverse) {Joystick1.setXAxis(XAxis);}             //  The input is normal (due to mounting of the sensor)
    else {Joystick1.setXAxis(1024-XAxis);}                   //  The input is reversed (due to mounting of the sensor)

  ZAxis = analogRead(A2);
  if (ZAxisReverse) {Joystick1.setZAxis(ZAxis);}             //  The input is normal (due to mounting of the sensor)
    else {Joystick1.setZAxis(1024-ZAxis);}                   //  The input is reversed (due to mounting of the sensor)

  Trim = analogRead(A3);
  if (TrimReverse) {Joystick2.setYAxis(Trim);}             //  The input is normal (due to mounting of the sensor)
    else {Joystick2.setYAxis(1024-Trim);}                   //  The input is reversed (due to mounting of the sensor)

  Airbrake = analogRead(A4);
  if (Airbrake > MaxAirbrake) {MaxAirbrake = Airbrake;}  //  Finding out the max Airbrake value since boot
  if (Airbrake < MinAirbrake) {MinAirbrake = Airbrake;}  //  Finding out the min Airbrake value since boot
  AirbrakeRatio = ((float)Airbrake-(float)MinAirbrake)/((float)MaxAirbrake - (float)MinAirbrake);   // Calculating the degree of deployed Airbrake (throttle)
  if (AirbrakeReverse) {Joystick2.setXAxis(Airbrake);}             //  The input is normal (due to mounting of the sensor)
    else {Joystick2.setXAxis(1024-(Airbrake));}                   //  The input is reversed (due to mounting of the sensor)
  if (WheelBrakeOnAirbrake) //  Emulating the wheelbrake (the Airbrake axis is used for the Airbrakes)
    {Joystick1.setButton(14,(AirbrakeRatio > 0.99));
    if (AirbrakeRatio > 0.99) {Serial.println("WheelBrake!");}}         //  If the Airbrake is deployed more than 95%, then the wheelbrake is activated.

  if (DebugMode) {                    // Sending debug information to the serial port
    Serial.print(", pitch: ");
    Serial.print(XAxis);
    Serial.print(", roll: ");
    Serial.print(YAxis);
    Serial.print(", rudder: ");
    Serial.print(ZAxis);
    Serial.print(", brake: ");
    Serial.print(Airbrake);
    Serial.print(", trim: ");
    Serial.println(Trim);
  }

  Joystick1.setThrottle(int(0));     //  Setting the output to the joystick output
  Joystick1.setRudder(int(0));       //  Setting the output to the joystick output
  Joystick2.setThrottle(int(0));     //  Setting the output to the joystick output
  Joystick2.setRudder(int(0));       //  Setting the output to the joystick output

  //  Digital signals. Note: the digital pinputs are reversed due to the signal is set to ground
  //                                            Button in software, signal in Arduino, button in Windows
  Joystick1.setButton(0,(not digitalRead(0)));   //     0                       D0              1
  Joystick1.setButton(1,(not digitalRead(1)));   //     1                       D1              2       
  Joystick1.setButton(2,(not digitalRead(2)));   //     2                       D2              3       
  Joystick1.setButton(3,(not digitalRead(3)));   //     3                       D3              4       
  Joystick1.setButton(4,(not digitalRead(4)));   //     4                       D4              5       
  Joystick1.setButton(5,(not digitalRead(5)));   //     5                       D5              6       
  Joystick1.setButton(6,(not digitalRead(6)));   //     6                       D6              7       
  Joystick1.setButton(7,(not digitalRead(7)));   //     7                       D7              8       
  Joystick1.setButton(8,(not digitalRead(8)));   //     8                       D8              9       
  Joystick1.setButton(9,(not digitalRead(9)));   //     9                       D9              10       
  Joystick1.setButton(10,(not digitalRead(10))); //     10                      D10             11       
  Joystick1.setButton(11,(not digitalRead(11))); //     11                      D11             12       
  Joystick1.setButton(12,(not digitalRead(12))); //     12                      D12             13       
  Joystick1.setButton(13,(not digitalRead(13))); //     13                      D13             14       
  
  delay(20);
  }

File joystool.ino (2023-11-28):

// Program bespoke to the JoyStool
// Arduino Micro or Leonardo
//
// avionics@skyracer.net
//
// 0.1 - First version
// 0.2 - Added comments and configurable variable
//
//------------------------------------------------------------

#include <Joystick.h> // https://github.com/gmarty2000-ARDUINO/arduino-JOYSTICK

Joystick_ Joystick(0x03, //hid report id
  JOYSTICK_TYPE_GAMEPAD, //joystick type
  12, //button count
  0, //Hsw 0-2
  true, //x
  true, //y
  true, //z
  false, //rx
  false, //ry
  false, //rz
  false, //rudder
  true, //throttle
  false, //accelerator
  false, //brake
  false); //steering

  // Konfiguration variables, FALSE: not reverse, TRUE: reversed
  bool XAxisReverse = false;
  bool YAxisReverse = true;
  bool ZAxisReverse = true;
  bool ThrottleReverse = true;

  // Initialize internal variables
  int Throttle = 0;
  int MaxThrottle = 0;
  int MinThrottle = 1024;
  float ThrottleRatio = 0.0;
  int XAxis = 0;
  int MaxXAxis = 0;
  int MinXAxis = 1024;
  float XRatio = 0.0;
  int YAxis = 0;
  int MaxYAxis = 0;
  int MinYAxis = 1024;  
  float YRatio = 0.0;
  int ZAxis = 0;
  int MaxZAxis = 0;
  int MinZAxis = 1024;
  float ZRatio = 0.0;
  
void setup() 
  {
  // Starting the joystick engine
  Joystick.begin();
  // Setting up IO´s
  pinMode(2, INPUT_PULLUP);
  pinMode(3, INPUT_PULLUP);
  pinMode(4, INPUT_PULLUP);
  pinMode(5, INPUT_PULLUP);
  pinMode(6, INPUT_PULLUP);
  pinMode(7, INPUT_PULLUP);
  pinMode(8, INPUT_PULLUP);
  pinMode(9, INPUT_PULLUP);
  pinMode(10, INPUT_PULLUP);
  pinMode(11, INPUT_PULLUP);
  pinMode(12, INPUT_PULLUP);
  }

void loop() 
  {
  //  Reading analog signals
  if (XAxisReverse) {XAxis = analogRead(A1);}             //  The input is normal (due to mounting of the sensor)
    else {XAxis = 1024-analogRead(A1);}                   //  The input is reversed (due to mounting of the sensor)

  if (YAxisReverse) {YAxis = (analogRead(A2)*0.9)-200;}   //  The input is normal (due to mounting of the sensor)
    else {YAxis = 1024-((analogRead(A2)*0.9)-200);}       //  The input is reversed (due to mounting of the sensor)

  if (ZAxisReverse) {ZAxis = analogRead(A3);}             //  The input is normal (due to mounting of the sensor)
    else {ZAxis = 1024-analogRead(A3);}                   //  The input is reversed (due to mounting of the sensor)

  if (ThrottleReverse)
  {Throttle = analogRead(A4);}                            //  The input is reversed due to mounting of the sensor
  else {Throttle = 1024-analogRead(A4);}                  //  The input is reversed due to mounting of the sensor

  //  Adjusting the output in relation to the minimum and maximum input
  // The X-axis
  if (XAxis > MaxXAxis) {MaxXAxis = XAxis;}     //  Finding maximum input
  if (XAxis < MinXAxis) {MinXAxis = XAxis;}     //  Finding minimum input
  XRatio = ((float)XAxis-(float)MinXAxis)/((float)MaxXAxis - (float)MinXAxis);  // Calculating the current ratio
  Joystick.setXAxis(int(XRatio * 1024));        //  Setting the output to the joystick output

  // The Y-axis
  if (YAxis > MaxYAxis) {MaxYAxis = YAxis;}     //  Finding maximum input
  if (YAxis < MinYAxis) {MinYAxis = YAxis;}     //  Finding minimum input
  YRatio = ((float)YAxis-(float)MinYAxis)/((float)MaxYAxis - (float)MinYAxis);  // Calculating the current ratio
  Joystick.setYAxis(int(YRatio * 1024));        //  Setting the output to the joystick output

  // The Z-axis
  if (ZAxis > MaxZAxis) {MaxZAxis = ZAxis;}     //  Finding maximum input
  if (ZAxis < MinZAxis) {MinZAxis = ZAxis;}     //  Finding minimum input
  ZRatio = ((float)ZAxis-(float)MinZAxis)/((float)MaxZAxis - (float)MinZAxis);  // Calculating the current ratio
  Joystick.setZAxis(int(ZRatio * 1024));        //  Setting the output to the joystick output

  // The thottle a.k.a. airbrake
  if (Throttle > MaxThrottle) {MaxThrottle = Throttle;}  //  Finding out the max throttle value since boot
  if (Throttle < MinThrottle) {MinThrottle = Throttle;}  //  Finding out the min throttle value since boot
  ThrottleRatio = ((float)Throttle-(float)MinThrottle)/((float)MaxThrottle - (float)MinThrottle);   // Calculating the degree of deployed throttle (airbrake)
  Joystick.setThrottle(int(ThrottleRatio * 1024));       //  Setting the output to the joystick output
  
  //  Emulating the wheelbrake (the throttle axis is used for the airbrakes)
  Joystick.setButton(11,(ThrottleRatio > 0.95));         //  If the throttle (airbrakes) is deployed more than 95%, then the wheelbrake is activated.

  //  Digital signals
  Joystick.setButton(0,(not digitalRead(2)));   //  Note: the digital pinputs are reversed due to the signal is set to ground
  Joystick.setButton(1,(not digitalRead(3))); 
  Joystick.setButton(2,(not digitalRead(4))); 
  Joystick.setButton(3,(not digitalRead(5))); 
  Joystick.setButton(4,(not digitalRead(6))); 
  Joystick.setButton(5,(not digitalRead(7))); 
  Joystick.setButton(6,(not digitalRead(8))); 
  Joystick.setButton(7,(not digitalRead(9))); 
  Joystick.setButton(8,(not digitalRead(10))); 
  Joystick.setButton(9,(not digitalRead(11))); 
  Joystick.setButton(10,(not digitalRead(12))); 
  
  //  Debugging
  //Serial.print("X: ");
  //Serial.print(XAxis);
  //Serial.print(", XRatio: ");
  //Serial.print(int(XRatio * 1024));
  //Serial.print(", MaxX: ");
  //Serial.print(MaxXAxis);
  //Serial.print(", MinX: ");
  //Serial.println(MinXAxis);
  //Serial.print(", Y: ");
  //Serial.print(int(YRatio * 1024));
  //Serial.print(", Z: ");
  //Serial.print(int(ZRatio * 1024));
  //Serial.print(", A4: ");
  //Serial.println(int(ThrottleRatio * 1024));

  delay(50);
  }

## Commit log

2024-10-23 Update and rename electronics_BOM.txt to BOM.txt
2024-12-03 Update and rename Trimplatts.stl to Trimplatta.stl
    [Trimplatta.stl]
2024-12-04 Update and rename Gångstångsbotten.stl to G1.stl
    [G1.stl]
2024-12-04 Update and rename Lagerhållare.stl to G2.stl
    [G2.stl]
2024-12-04 Update and rename LagerBricka.stl to G3.stl
    [G3.stl]
2024-12-04 Update and rename Trimplatta.stl to H1.stl
    [H1.stl]
2024-12-04 Update and rename knappplatta.stl to H2.stl
    [H2.stl]
2024-12-05 Update and rename F2.stl to F3.stl
    [F3.stl]
2024-12-31 Update and rename dxf/B10.dxf to dxf/old/B10.dxf
    [B10.dxf]
2024-12-31 Update and rename dxf/C3.dxf to dxf/old/C3.dxf
    [C3.dxf]
2024-12-31 Update and rename dxf/C2.dxf to dxf/old/C2.dxf
    [C2.dxf]
2024-12-31 Update and rename dxf/C1.dxf to dxf/old/C1.dxf
    [C1.dxf]
2024-12-31 Update and rename dxf/A9.dxf to dxf/old/A9.dxf
    [A9.dxf]
2024-12-31 Update and rename dxf/D1.dxf to dxf/old/D1.dxf
    [D1.dxf]
2024-12-31 Update and rename dxf/B6.dxf to dxf/old/B6.dxf
    [B6.dxf]
2025-09-29 Update and rename dxf/B10a.dxf to dxf/old/B10a.dxf
    [B10a.dxf]
2025-10-12 Update and rename H6.stl to H5.stl
    [H5.stl]
2025-10-12 Update and rename H7.stl to H6.stl
    [H6.stl]
2025-10-24 Update and rename dxf/A1.dxf to dxf/old/A1.dxf
    [A1.dxf]
2025-10-24 Update and rename dxf/A2.dxf to dxf/old/A2.dxf
    [A2.dxf]
2025-10-24 Update and rename dxf/A3.dxf to dxf/old/A3.dxf
    [A3.dxf]
2025-10-24 Update and rename dxf/A4.dxf to dxf/old/A4.dxf
    [A4.dxf]
2025-10-24 Update and rename dxf/A5.dxf to dxf/old/A5.dxf
    [A5.dxf]
2025-10-24 Update and rename dxf/A6.dxf to dxf/old/A6.dxf
    [A6.dxf]
2025-10-24 Update and rename dxf/A7.dxf to dxf/old/A7.dxf
    [A7.dxf]
2025-10-24 Update and rename dxf/A8.dxf to dxf/old/A8.dxf
    [A8.dxf]
2025-10-24 Update and rename dxf/A9a.dxf to dxf/old/A9a.dxf
    [A9a.dxf]
2025-10-24 Update and rename dxf/B1.dxf to dxf/old/B1.dxf
    [B1.dxf]
2025-10-24 Update and rename dxf/B10b.dxf to dxf/old/B10b.dxf
    [B10b.dxf]
2025-10-24 Update and rename dxf/B2.dxf to dxf/old/B2.dxf
    [B2.dxf]
2025-10-24 Update and rename dxf/B3.dxf to dxf/old/B3.dxf
    [B3.dxf]
2025-10-24 Update and rename dxf/B4.dxf to dxf/old/B4.dxf
    [B4.dxf]
2025-10-24 Update and rename dxf/B5.dxf to dxf/old/B5.dxf
    [B5.dxf]
2025-10-24 Update and rename dxf/B6a.dxf to dxf/old/B6a.dxf
    [B6a.dxf]
2025-10-24 Update and rename dxf/B7.dxf to dxf/old/B7.dxf
    [B7.dxf]
2025-10-24 Update and rename dxf/B8.dxf to dxf/old/B8.dxf
    [B8.dxf]
2025-10-24 Update and rename dxf/B9.dxf to dxf/old/B9.dxf
    [B9.dxf]
2025-10-24 Update and rename dxf/C1a.dxf to dxf/old/C1a.dxf
    [C1a.dxf]
2025-10-24 Remove old C2a.dxf file
    [C2a.dxf]
2025-10-24 Update and rename dxf/C3a.dxf to dxf/old/C3a.dxf
    [C3a.dxf]
2025-10-24 Update and rename dxf/D1a.dxf to dxf/old/D1a.dxf
    [D1a.dxf]
2025-10-24 Update and rename dxf/D2.dxf to dxf/old/D2.dxf
    [D2.dxf]
2025-10-24 Update and rename dxf/D3.dxf to dxf/old/D3.dxf
    [D3.dxf]
2025-10-24 Update and rename dxf/D4.dxf to dxf/old/D4.dxf
    [D4.dxf]
2025-10-24 Remove old D5.dxf file
    [D5.dxf]
2025-10-24 Update and rename dxf/D6.dxf to dxf/old/D6.dxf
    [D6.dxf]
2025-10-24 Update and rename dxf/E1.dxf to dxf/old/E1.dxf
    [E1.dxf]
2025-10-24 Update and rename dxf/E2.dxf to dxf/old/E2.dxf
    [E2.dxf]
2025-10-24 Update and rename dxf/E3.dxf to dxf/old/E3.dxf
    [E3.dxf]
2025-10-24 Update and rename dxf/E4.dxf to dxf/old/E4.dxf
    [E4.dxf]
2025-10-24 Update and rename dxf/E5.dxf to dxf/old/E5.dxf
    [E5.dxf]
2025-10-24 Update and rename dxf/E6.dxf to dxf/old/E6.dxf
    [E6.dxf]
2025-10-24 Update and rename dxf/E7.dxf to dxf/old/E7.dxf
    [E7.dxf]
2025-10-24 Update and rename dxf/E8.dxf to dxf/old/E8.dxf
    [E8.dxf]
2025-10-24 Update and rename dxf/E9.dxf to dxf/old/E9.dxf
    [E9.dxf]
2025-10-26 Remove old H2.stl file
    [H2.stl]
2025-10-28 Update README with YAS-chairs prototype status
    Added details about the current status of YAS-chairs and updated prototype series information.
2025-10-28 Revise project status and add prototype images
    Updated the project status section with details on built YAS-chairs and added images of prototypes.
2025-12-02 Clarify prototype status and add images
    Updated text to clarify the status of the prototype series and added images.
